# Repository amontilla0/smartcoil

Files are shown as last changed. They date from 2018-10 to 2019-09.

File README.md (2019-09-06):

# SmartCoil

Python (https://www.python.org/)
Raspberry Pi (https://www.raspberrypi.org/)
Amazon Alexa (https://developer.amazon.com/alexa)

Full interface to automate a home-based fan coil unit with a Raspberry Pi.

**DISCLAIMER:** Notice that fan coil unit wiring may involve high voltage manipulation, any handling of this kind is under your own responsibility.

Pictures of the GUI and home-made case views are listed below.

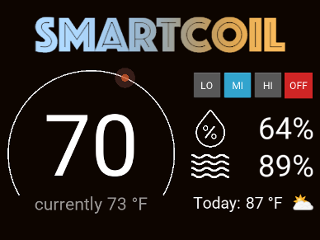
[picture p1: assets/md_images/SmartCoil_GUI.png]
Smartcoil GUI
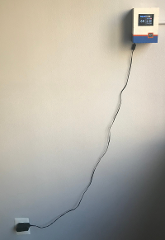
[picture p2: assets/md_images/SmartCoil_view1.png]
Smartcoil case Front view
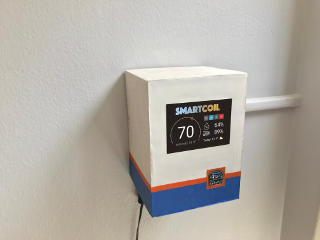
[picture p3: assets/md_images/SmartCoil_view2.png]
Smartcoil case side view
[]() []() []()

This project is based in the following technologies:

- Kivy for GUI that allows temperature and fan speed manipulation through a PiTFT touch screen.
- BME680 sensor for current temperature, humidity and air quality information in the GUI.
- 4-channel relay module to control coil valve and fan states.
- Meteorologisk institutt weather API for additional information such as outdoors temperature and weather forecast in the GUI.
- Flask for server deployment + Pagekite for HTTPS tunneling to control the app through an Alexa Smart Home Skill.

## Physical configuration

The **BME680 sensor** is wired as follows:
- Pi 3V3 to sensor VIN
- Pi GND to sensor GND
- Pi SCL to sensor SCK
- Pi SDA to sensor SDI

The **4-channel relay module** is wired as follows:
- Pi 5V to module VCC
- Pi GND to module GND
- PI GPIO 17 to module IN1 (water valve control)
- PI GPIO 22 to module IN2 (fan lo-speed control)
- PI GPIO 23 to module IN3 (fan mi-speed control)
- PI GPIO 27 to module IN4 (fan hi-speed control)

For a graphic reference, refer to the schematic below.

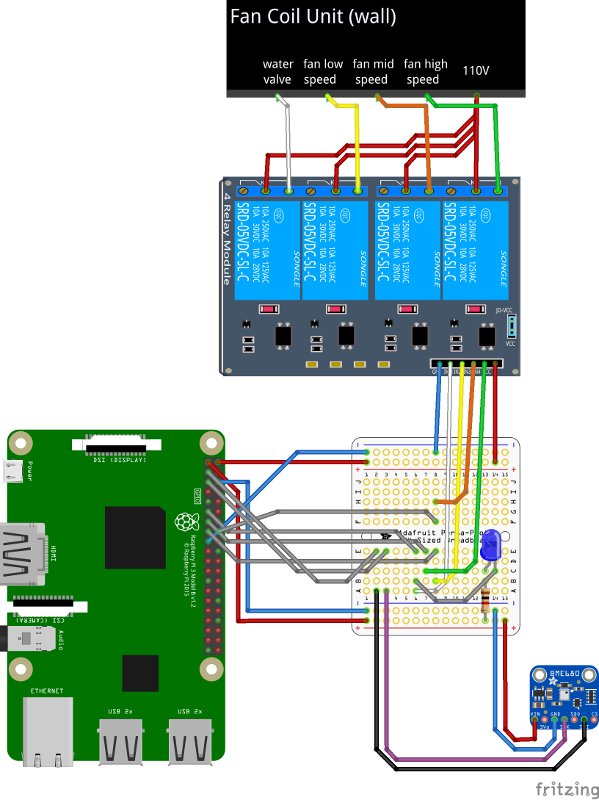
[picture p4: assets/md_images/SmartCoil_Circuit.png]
Smartcoil Circuit Sketch
[]()

## Amazon Alexa configuration
In order to use the Alexa portion of the project, you must build your own Alexa smart home skill. You could follow the official guide on [Steps to Build a Smart Home Skill](https://developer.amazon.com/docs/smarthome/steps-to-build-a-smart-home-skill.html) and use the code I implemented for my own skill, found in [here](https://github.com/amontilla0/smartcoil/blob/master/assets/alexa_nodejs/index.js).

Create a new account on [pagekite](https://pagekite.net/) (they have a free trial) to enable HTTPS tunneling and do the following configuration:
- In the index.js file for AWS lambda, update the constant ``tok`` with a unique secret token.
- In the project, rename server_config.json_template to server_config.json (located in assets/config) and assign the values ``tunnel``, ``port`` and ``token`` to the your new pagekite server, pagekite port and secret token created in the previous step, respectively.

## Database details
An internal SQLite database is used to store outdoor and indoor status for future data analysis.
The items stored in the DB are:
- Temperature, humidity, air pressure, gas resistance and air quality, coming from the BME680 sensor.
- Current state of the GUI such as target temperature and set fan speed.
- Latitude, longitude, outdoor temperature, humidity, pressure, forecast condition, wind speed, wind direction and precipitation percentage. All coming from the weather API.

## Installation and usage

For a quick run of the project, clone the repository and execute the commands below at the root directory. It is recommended to use a virtual environment created with ``virtualenv``.

```bash
pip install -r requirements.txt
python3 tests/main_test.py
```

# Additional resources
To see the SmartCoil in action, please refer to the following video:

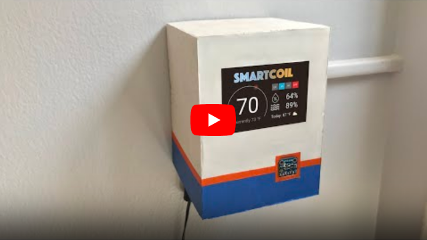
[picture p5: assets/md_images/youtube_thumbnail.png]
SmartCoil in action (https://www.youtube.com/watch?v=cOHOSmqagjc)


You could also read this [article](https://medium.com/voice-tech-podcast/making-a-smart-thermostat-for-an-old-fan-coil-unit-fcu-36c078e2d544) for more details on how I built this project at home.

## License
[MIT](https://choosealicense.com/licenses/mit/)

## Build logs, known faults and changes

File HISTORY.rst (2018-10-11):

=======
History
=======

0.1.0 (2018-10-10)
------------------

* First alfa product

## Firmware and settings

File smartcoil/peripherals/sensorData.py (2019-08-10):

import bme680
import time
from ..utils import utils

class SensorData:
    '''Serves as the class that periodically fetches information from the BME680
    sensor.'''

    def __init__(self, outqueue = None, burn_time = 300):
        '''The module is intented to be a secondary thread of the base class
        SmartCoil.
        To allow communication between the main thread and this thread, a Queue
        can be passed as an argument.
        Additionally, the BME680 needs a period of burning time to prime the gas
        sensor and read accurate air quality values. A specific amount of time
        to prime the gas sensor can be passed as an argument too.

        Args:
            outqueue (:obj:`Queue`, optional): Outbound queue to send messages
                to the main thread.
            burn_time (int): Time in seconds to allow the sensor to burn before
                sending accurate readings. Defaults to 5 minutes.
        '''
        try:
            self.outbound_queue = outqueue
            self.sensor = bme680.BME680(bme680.I2C_ADDR_PRIMARY)
             #3.32
        except IOError:
            self.sensor = bme680.BME680(bme680.I2C_ADDR_SECONDARY)

        # sensor initial calibration
        for name in dir(self.sensor.calibration_data):
            if not name.startswith('_'):
                value = getattr(self.sensor.calibration_data, name)

        # These oversampling settings can be tweaked to
        # change the balance between accuracy and noise in
        # the data.
        self.sensor.set_humidity_oversample(bme680.OS_2X)
        self.sensor.set_pressure_oversample(bme680.OS_4X)
        self.sensor.set_temperature_oversample(bme680.OS_8X)
        self.sensor.set_filter(bme680.FILTER_SIZE_3)
        self.sensor.set_gas_status(bme680.ENABLE_GAS_MEAS)

        # Up to 10 heater profiles can be configured, each
        # with their own temperature and duration.
        # sensor.set_gas_heater_profile(200, 150, nb_profile=1)
        # sensor.select_gas_heater_profile(1)
        self.sensor.set_gas_heater_temperature(320)
        self.sensor.set_gas_heater_duration(150)
        self.sensor.select_gas_heater_profile(0)

        # for building up gas resistance baseline
        self.start_time = time.time()
        self.curr_time = time.time()
        self.burn_in_time = burn_time
        self.burn_in_data = []
        self.gas_baseline = None
        self.burn_complete = False

        # Set the humidity baseline to 40%, an optimal indoor humidity.
        self.hum_baseline = 40.0
        # This sets the balance between humidity and gas reading in the
        # calculation of air_quality_score (25:75, humidity:gas)
        self.hum_weighting = 0.25

    def build_gas_baseline(self):
        ''' Primes the gas sensor based on the specified burning time in
        seconds.
        Once the time has passed, the gas baseline is built and the gas readings
        are ready to be used.
        '''
        if self.sensor_ready(): return

        if self.curr_time - self.start_time < self.burn_in_time:
            self.curr_time = time.time()
            if self.sensor.data.heat_stable:
                gas = self.sensor.data.gas_resistance
                self.burn_in_data.append(gas)
        else:
            self.burn_complete = True

        if self.burn_complete and self.gas_baseline is None:
            self.gas_baseline =  sum(self.burn_in_data[-50:]) / 50.0

    # Checks if the gas baseline is already initialized, a process that takes
    # 5 minutes of initial readings to happen.
    def sensor_ready(self):
        '''Verifies if the gas baseline has been built already (after consuming
        the specified burning time).

        Returns:
            bool: Whether the gas baseline was built or not.
        '''
        return self.gas_baseline is not None

    def calc_air_quality(self):
        '''Calculates the air quality based on readings processing data from gas
        and humidity sensors.

        Returns:
            int: Either -1 if the gas baseline is still not built,
                or a float representing the indoor air quality percentage.
        '''
        air_quality_score = -1

        if  self.sensor_ready() and self.sensor.data.heat_stable:
            gas = self.sensor.data.gas_resistance
            gas_offset = self.gas_baseline - gas

            hum = self.sensor.data.humidity
            hum_offset = hum - self.hum_baseline

            # Calculate hum_score as the distance from the hum_baseline.
            if hum_offset > 0:
                hum_score = (100 - self.hum_baseline - hum_offset)
                hum_score /= (100 - self.hum_baseline)
                hum_score *= (self.hum_weighting * 100)
            else:
                hum_score = (self.hum_baseline + hum_offset)
                hum_score /= self.hum_baseline
                hum_score *= (self.hum_weighting * 100)

            # Calculate gas_score as the distance from the gas_baseline.
            if gas_offset > 0:
                gas_score = (gas / self.gas_baseline)
                gas_score *= (100 - (self.hum_weighting * 100))
            else:
                gas_score = 100 - (self.hum_weighting * 100)

            air_quality_score = int(hum_score + gas_score)

        return air_quality_score

    def get_most_recent_readings(self, temp_in_f = True):
        '''Gets the most recent values fetched from the BME680 sensor, these
        values are:
            - temperature
            - pressure
            - humidity
            - gas resistance
            - air quality

        Args:
            temp_in_f (bool, optional): Specifies if the temperature must be
                specified in Fahrenheit. Defaults to True.

        Returns:
            list: A list with values fetched from the BME680 sensor, in the
            following order:
                temperature, pressure, humidity, gas resistance, air quality.
        '''
        if not self.sensor_ready(): return None

        temp = self.sensor.data.temperature
        if temp_in_f:
            temp = utils.c_to_f(temp)
        pres = self.sensor.data.pressure
        humi = self.sensor.data.humidity
        gas_res = self.sensor.data.gas_resistance
        airq = self.calc_air_quality()
        airq = '-' if airq < 0 else airq

        return [temp, pres, humi, gas_res, airq]

    def run_sensor(self, verbose = False, exit_evt = None, temp_in_f = True):
        '''The main loop that constantly fetches information from the BME680
        sensor.

        Args:
            verbose (bool, optional): Whether using this method should print the
                readings every second to STDOUT.
            exit_evt (:obj:`Event`, optional): Event flag to manage sensor
                cleaning before exiting the full app.
            temp_in_f (bool, optional): Specifies if the temperature must be
                specified in Fahrenheit. Defaults to True.
        '''
        sleep_func = time.sleep if exit_evt == None else exit_evt.wait

        temp = self.sensor.data.temperature
        if temp_in_f:
            temp = utils.c_to_f(temp)
        # 'half-rounding' temperature to closest 0.5 increment
        temp = round(temp) - (round(temp) - int(temp))/2

        pres = int(self.sensor.data.pressure)
        humi = int(self.sensor.data.humidity)
        airq = self.calc_air_quality()
        airq = '-' if airq < 0 else int(airq)

        while True if exit_evt == None else not exit_evt.is_set():
            new_temp = self.sensor.data.temperature
            if temp_in_f:
                new_temp = utils.c_to_f(new_temp)
            real_temp = new_temp
            # 'half-rounding' temperature to closest 0.5 increment
            new_temp = round(new_temp) - (round(new_temp) - int(new_temp))/2

            new_pres = int(self.sensor.data.pressure)
            new_humi = int(self.sensor.data.humidity)
            new_airq = self.calc_air_quality()
            new_airq = '-' if new_airq < 0 else int(new_airq)

            # temperature offset in celcius after monitoring and comparing
            #aginst another thermometer.
            self.sensor.set_temp_offset(-1.9)

            if self.sensor.get_sensor_data():
                self.build_gas_baseline()

                values_changed = (new_temp != temp or
                                  new_pres != pres or
                                  new_humi != humi or
                                  new_airq != airq)

                if self.outbound_queue is not None and values_changed:
                    self.outbound_queue.put(utils.Message('SNSMSG'))

                if verbose:
                    output = ('temp: {0:.2f} F ({1:.3f}), pressure: {2:.1f} '
                    + 'hPa, humidity: {3:.0f}%, air quaility: {4}%').format(
                        temp, real_temp,
                        pres,
                        humi,
                        airq)

                    print(output)

            # update last seen values
            temp = new_temp
            pres = new_pres
            humi = new_humi
            airq = new_airq

            sleep_func(1)

        if self.outbound_queue is not None:
            self.outbound_queue.put(utils.Message('EXIT'))

if __name__=='__main__':
    sd = SensorData()
    sd.run_sensor(True)

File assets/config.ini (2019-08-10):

[kivy]
keyboard_repeat_delay = 300
keyboard_repeat_rate = 30
log_dir = logs
log_enable = 1
log_level = warning
log_name = kivy_%y-%m-%d_%_.txt
window_icon = 
keyboard_mode = 
keyboard_layout = qwerty
desktop = 1
exit_on_escape = 1
pause_on_minimize = 0
kivy_clock = default
default_font = ['Roboto', 'data/fonts/Roboto-Regular.ttf', 'data/fonts/Roboto-Italic.ttf', 'data/fonts/Roboto-Bold.ttf', 'data/fonts/Roboto-BoldItalic.ttf']
log_maxfiles = 100
window_shape = data/images/defaultshape.png
config_version = 21

[graphics]
display = -1
fullscreen = 0
height = 600
left = 0
maxfps = 60
multisamples = 2
position = auto
rotation = 0
show_cursor = 1
top = 0
width = 800
resizable = 1
borderless = 0
window_state = visible
minimum_width = 0
minimum_height = 0
min_state_time = .035
allow_screensaver = 1
shaped = 0

[input]
mouse = mouse
mtdev_%(name)s = probesysfs,provider=mtdev,param=rotation=270,param=invert_y=1
hid_%(name)s = probesysfs,provider=hidinput

[postproc]
double_tap_distance = 20
double_tap_time = 250
ignore = []
jitter_distance = 0
jitter_ignore_devices = mouse,mactouch,
retain_distance = 50
retain_time = 0
triple_tap_distance = 20
triple_tap_time = 375

[widgets]
scroll_timeout = 250
scroll_distance = 20
scroll_friction = 1.
scroll_stoptime = 300
scroll_moves = 5

[modules]

[network]
useragent = curl

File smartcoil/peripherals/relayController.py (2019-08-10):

import RPi.GPIO as GPIO
from time import sleep

# Flag values for turning on or off a relay.
VAL_ON = False
VAL_OFF = True
# Relays identifiers
valve = 0
fanlo = 1
fanmi = 2
fanhi = 3

class RelayController():
    '''Serves as the class that controls the 4-channel relay module that deals
    directly with the Fan Coil Unit (FCU).'''

    def __init__(self):
        '''The module is intented to be a secondary thread of the base class
        SmartCoil.
        For this project, I use a 4 relay module to control a decades-old FCU.
        All GPIO pins below follow BCM numbering:
            - Relay 1 makes use of pin 17 and controls the valve.
            - Relay 2 makes use of pin pin 22 and controls the fan's low speed.
            - Relay 3 is controlled by pin 23 and controls the fan's mid speed.
            - Relay 4 is controlled by pin 27 and controls the fan's high speed.
        '''
        self.relays = [17,22,23,27]
        self.RELAYS_COUNT = len(self.relays)
        self.init()

    def set_relay_to(self, rel, value):
        '''Sets the value for a given relay.

        Args:
            rel (int): The desired relay to control, values go from 0 to 3.
            value (bool): Either True to turn on a signal, or False for the
                opposite.
        '''

        GPIO.output(self.relays[rel],value)

    # Turns the fancoil on or off.
    # speed goes from 1 to 3. 0 means turned off.
    def start_coil_at(self, speed):
        '''Sets the speed for the FCU.

        Args:
            speed (int): 1 for low speed, 2 for mid speed and 3 for high speed.
                The value 0 turns off the FCU.
        '''
        options = [0, fanlo, fanmi, fanhi]
        self.all_off()
        if speed > 0:
            self.set_relay_to(valve, VAL_ON)
            self.set_relay_to(options[speed], VAL_ON)

    def fancoil_is_on(self):
        '''Checks if the FCU is turned on.

        Returns:
            boolean: True if the valve relay is on, False otherwise.
        '''
        return GPIO.input(self.relays[valve]) == VAL_ON

    # Set all relays to a value.
    def set_all_to(self, value):
        '''Helper method to turn all the relays to the same value. Useful to
        turn everything off.

        Args:
            value (int): The desired value (on or off) to set all the relays to.
        '''
        for r in range(self.RELAYS_COUNT):
            self.set_relay_to(r, value)

    def all_off(self):
        '''Turns all the relays to off.'''
        self.set_all_to(VAL_OFF)

    def init(self):
        '''Initializer helper method. Used in this class constructor.'''
        # Use board GPIO numbering
        GPIO.setmode(GPIO.BCM)
        # Setting pins to OUT mode
        for r in self.relays:
            GPIO.setup(r, GPIO.OUT)
        self.all_off()

    def cleanup(self):
        '''Clean up helper method. Use it before leaving the application.'''
        self.all_off()
        GPIO.cleanup()

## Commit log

2018-10-11 Initial product that periodically stores indoor and outdoor conditions into database (sqlite).
    - external conditions are polled with yr weather (https://www.yr.no/) API.
    - internal conditions such as temperature, humidity, pressure, gas resistance and air quality are derived from a BME680 sensor controlled by a Raspberry Pi.
    - future commits will also include a GUI based in kivy, which is already included as a required module for this project.
2019-06-18 Adding initial code for Graphic User Interface using Kivy library. This code makes use of a PiTFT (touchscreen) to set temperature as well as monitoring internal and external temperature.
2019-06-25 - Addition of a controller class that helps managing the relays with GPIO. - Internal refactoring of existing classes for better comunication. - Functionality additions.
2019-06-26 - Added interaction with RelayController class to turn the fancoil on and off with on-screen buttons. - Fan speed and off buttons refactored to use ToggleButton class.
2019-06-27 - Added SIGNINT event handling for closing the application after cleanup. - Improvement of monitoring temperature. - Improvement of GUI initialization. - Improvement of relay method controllers.
2019-06-28 - Dynamic offset improvement for temperature monitoring. - GUI initialization values improvement.
2019-06-28 First steps towards a listener approach, where SmartCoil class receives messages from other threads and is the only class responsible for executing actions like relay control or data persistence.
2019-06-29 - Improvements in sensor data class for a more accurate temperature reading by adjusting an offset. - Some refactoring for the new listener structure.
2019-06-30 Full implementation of listener structure with asyncio and can libraries. Now the SmartCoil class is the only one in charge of executing actions with the peripherals as well as persisting data.
2019-07-01 - Farenheit standarization along SensorData class. - Added feature to load last seen user config (temp and speed), when starting the application.
2019-07-02 - Full functionality achieved. Sensor and Weather data updated into the GUI as well as all information is being stored periodically into database.
2019-07-10 - refactored server by implementing a ServerManager class that loads both the tunnel and the Flask app. This is in preparation for SmartCoil class to run the server as an additional thread, handling 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
2019-07-11 small advances in bilateral communication with SmartCoil main thread. Considering moving from python-can to much cleaner Queue
2019-07-11 - addition of simple Message class used in thread communications
2019-07-13 - Python-can and asyncio approach fully replaced by the use of Queues. - Server integration with main app added. Next steps: implement full Alexa interacion with Smartcoil.
    [sensorData.py]
2019-07-16 - Dealing with log levels in the Kivy app through kivy config. Line in python KivySmartCoilGUI class no longer needed. - Adding documentation for SensorData following Google Style Python Docstrings (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
    [sensorData.py]
2019-07-21 - full documentation for relayController class.
2019-07-23 - Fixed the mode value for the server mock response (StateReport). - Added a missing attribute in the StateReport to properly inform about the fan speed to Alexa.
2019-07-30 - Addition of fritzing sketch for circuit layout.
    [SmartCoil_sketch.fzz]
2019-07-31 - Updates to fritzing circuit layout.
    [SmartCoil_sketch.fzz]
2019-08-01 - Updates to fritzing sketch.
    [SmartCoil_sketch.fzz]
2019-08-03 - Updates to fritzing circuit layout. - Final circuit image loaded.
    [SmartCoil_sketch.fzz]
